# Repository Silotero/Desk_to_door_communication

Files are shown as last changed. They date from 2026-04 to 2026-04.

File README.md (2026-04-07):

# Desk_to_door_communication

This is a 2-part project. Its purpose is to establish basic communication beetween a person that is sitting inside the room at his desk and a visitor standing outside his rooms door. It allows the person in the room to display certain information (such as what he is doing, is he busy, can the person outside easily enter) at a screen outside near the doors, for the visitor. The visitor can also send certain information such as announcing who he is, to the person at the desk. Also displayed at a small screen.
Other functions are a webhosted camera view of the outside of the room, a RFID tag reader that displays certain information on the screen after a readout and also plays a song on the speakers.

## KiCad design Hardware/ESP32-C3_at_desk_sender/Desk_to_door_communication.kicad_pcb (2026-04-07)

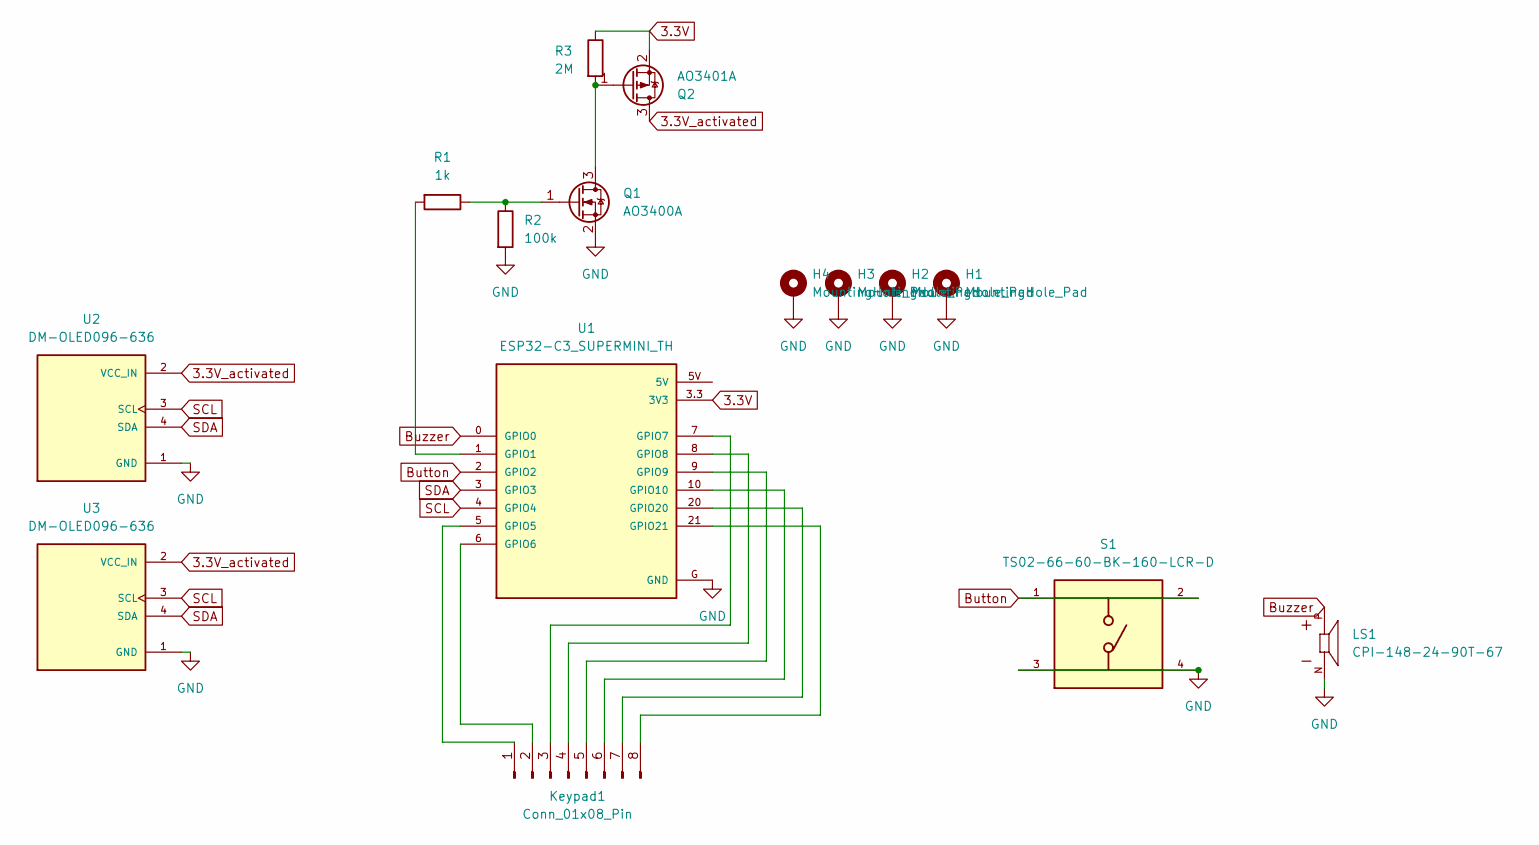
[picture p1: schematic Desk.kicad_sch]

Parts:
H1, H2, H3, H4: MountingHole_Pad; MountingHole_2.2mm_M2_DIN965_Pad_TopBottom
Keypad1: Conn_01x08_Pin; PinHeader_1x08_P2.54mm_Vertical
LS1: CPI-148-24-90T-67; XDCR_CPI-148-24-90T-67; PARTREV 1
Q1: AO3400A; SOT-23
Q2: AO3401A; SOT-23
R1: 1k; R_0805_2012Metric
R2: 100k; R_0805_2012Metric
R3: 2M; R_0805_2012Metric
S1: TS02-66-60-BK-160-LCR-D; SW_TS02-66-60-BK-160-LCR-D; PARTREV 1.0
U1: ESP32-C3_SUPERMINI_TH; MODULE_ESP32-C3_SUPERMINI_TH
U2, U3: DM-OLED096-636; MODULE_DM-OLED096-636; PARTREV 2018-09-10

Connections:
3.3V: Q2.2 (S), R3.1, U1.3.3 (3V3)
3.3V_activated: Q2.3 (D), U2.2 (VCC_IN), U3.2 (VCC_IN)
Button: S1.1, S1.2, U1.2 (GPIO2)
Buzzer: LS1.P, U1.0 (GPIO0)
GND: H1.1, H2.1, H3.1, H4.1, LS1.N, Q1.2 (S), R2.2, S1.3, S1.4, U1.G (GND), U2.1 (GND), U3.1 (GND)
unnamed: Keypad1.1, U1.5 (GPIO5)
unnamed: Keypad1.2, U1.6 (GPIO6)
unnamed: Keypad1.3, U1.7 (GPIO7)
unnamed: Keypad1.4, U1.8 (GPIO8)
unnamed: Keypad1.5, U1.9 (GPIO9)
unnamed: Keypad1.6, U1.10 (GPIO10)
unnamed: Keypad1.7, U1.20 (GPIO20)
unnamed: Keypad1.8, U1.21 (GPIO21)
unnamed: Q1.3 (D), Q2.1 (G), R3.2
unnamed: Q1.1 (G), R1.1, R2.1
unnamed: R1.2, U1.1 (GPIO1)
SCL: U1.4 (GPIO4), U2.3 (SCL), U3.3 (SCL)
SDA: U1.3 (GPIO3), U2.4 (SDA), U3.4 (SDA)

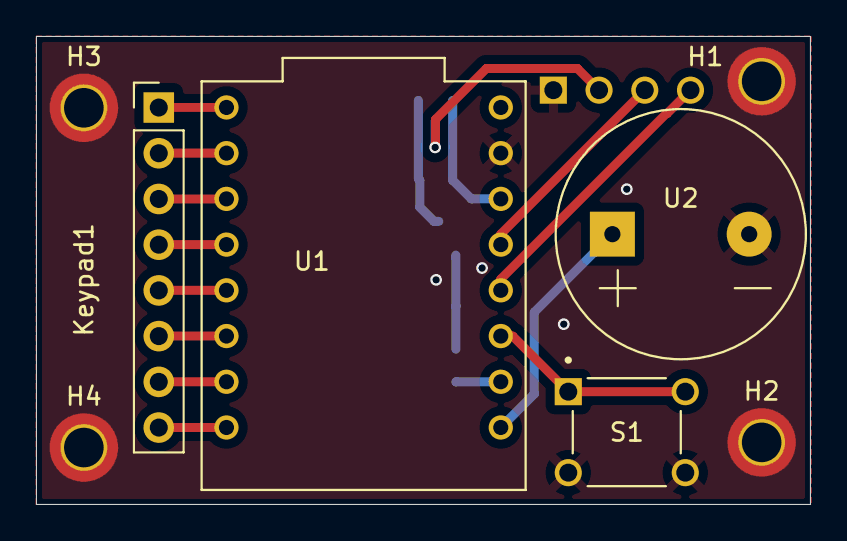
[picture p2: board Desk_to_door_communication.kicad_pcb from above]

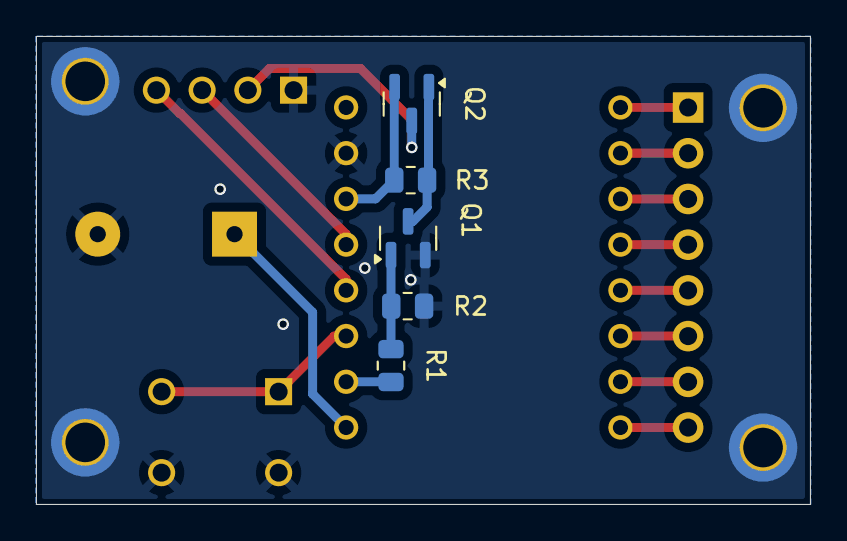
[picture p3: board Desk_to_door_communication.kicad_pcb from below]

Board: 2 copper layers, 43.0 x 26.0 mm, 14 parts (5 on the bottom side), 18 nets.

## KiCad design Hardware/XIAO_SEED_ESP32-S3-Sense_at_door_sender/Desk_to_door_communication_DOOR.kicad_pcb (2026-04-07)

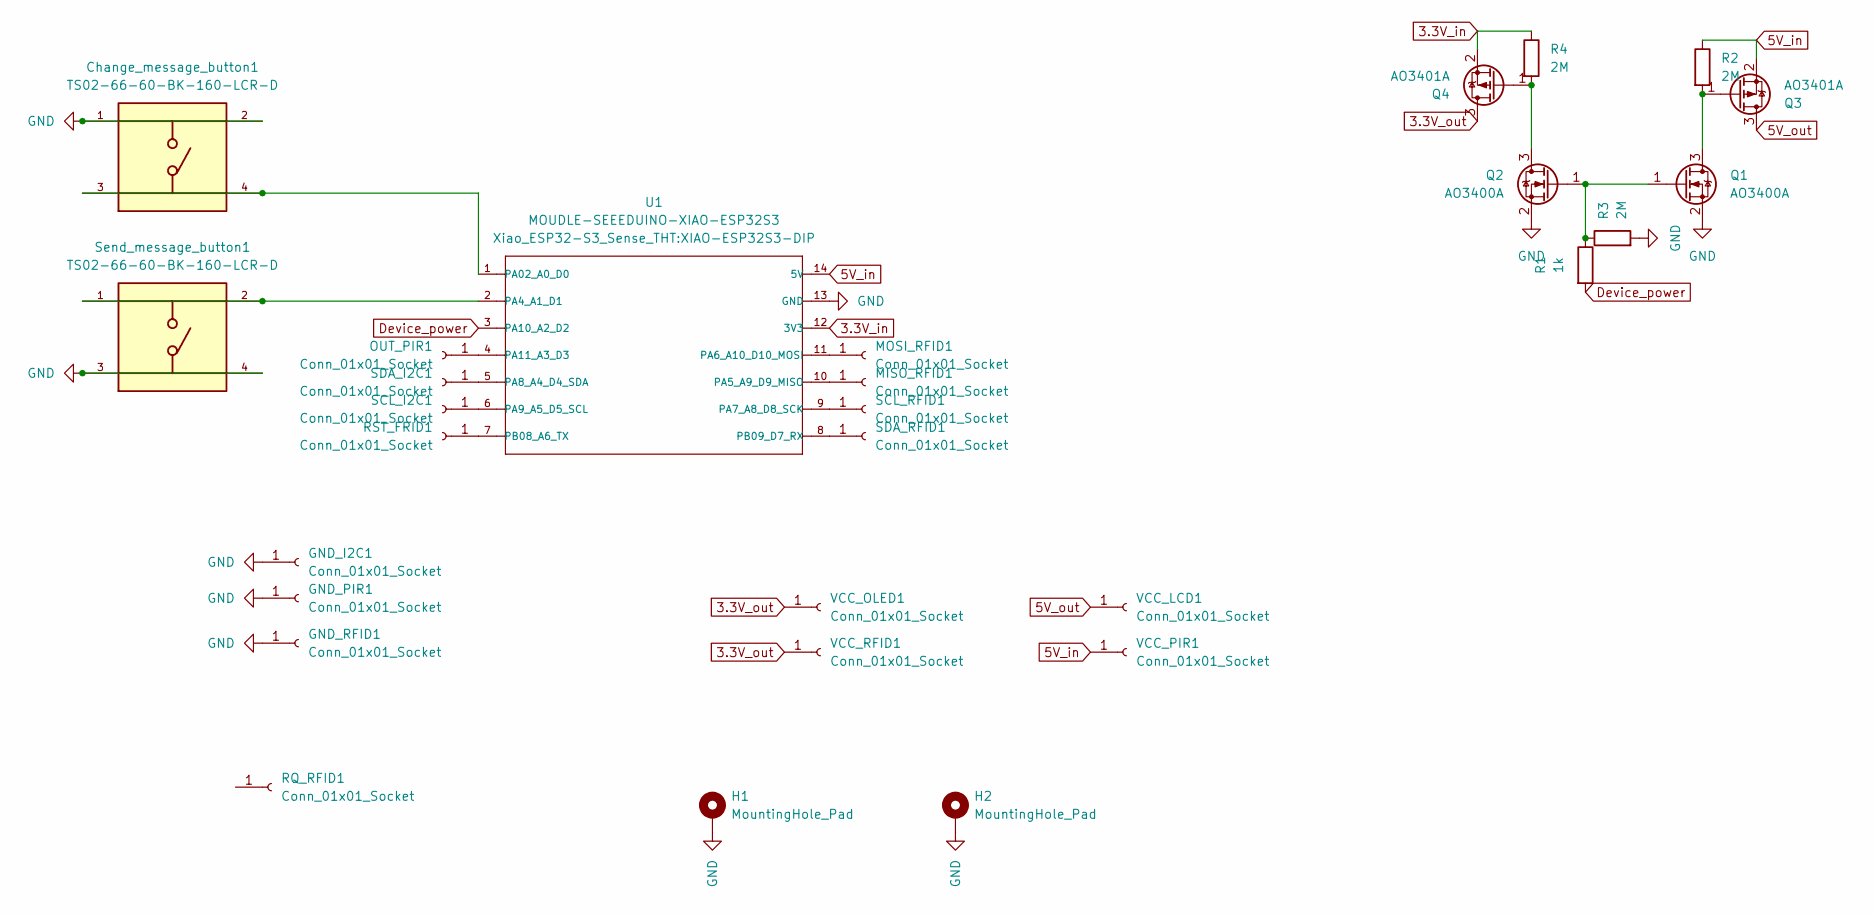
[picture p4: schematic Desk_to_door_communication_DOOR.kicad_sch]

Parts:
Change_message_button1: TS02-66-60-BK-160-LCR-D; SW_TS02-66-60-BK-160-LCR-D; PARTREV 1.0
GND_I2C1: Conn_01x01_Socket; Pin_D1.0mm_L10.0mm
GND_PIR1: Conn_01x01_Socket; Pin_D1.0mm_L10.0mm
GND_RFID1: Conn_01x01_Socket; Pin_D1.0mm_L10.0mm
H1, H2: MountingHole_Pad; MountingHole_2.2mm_M2_DIN965_Pad
MISO_RFID1: Conn_01x01_Socket; Pin_D1.0mm_L10.0mm
MOSI_RFID1: Conn_01x01_Socket; Pin_D1.0mm_L10.0mm
OUT_PIR1: Conn_01x01_Socket; Pin_D1.0mm_L10.0mm
Q1, Q2: AO3400A; SOT-23
Q3, Q4: AO3401A; SOT-23
R1: 1k; R_0805_2012Metric
R2, R3, R4: 2M; R_0805_2012Metric
RQ_RFID1: Conn_01x01_Socket; Pin_D1.0mm_L10.0mm
RST_FRID1: Conn_01x01_Socket; Pin_D1.0mm_L10.0mm
SCL_I2C1: Conn_01x01_Socket; Pin_D1.0mm_L10.0mm
SCL_RFID1: Conn_01x01_Socket; Pin_D1.0mm_L10.0mm
SDA_I2C1: Conn_01x01_Socket; Pin_D1.0mm_L10.0mm
SDA_RFID1: Conn_01x01_Socket; Pin_D1.0mm_L10.0mm
Send_message_button1: TS02-66-60-BK-160-LCR-D; SW_TS02-66-60-BK-160-LCR-D; PARTREV 1.0
U1: MOUDLE-SEEEDUINO-XIAO-ESP32S3; XIAO-ESP32S3-DIP
VCC_LCD1: Conn_01x01_Socket; Pin_D1.0mm_L10.0mm
VCC_OLED1: Conn_01x01_Socket; Pin_D1.0mm_L10.0mm
VCC_PIR1: Conn_01x01_Socket; Pin_D1.0mm_L10.0mm
VCC_RFID1: Conn_01x01_Socket; Pin_D1.0mm_L10.0mm

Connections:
3.3V_in: Q4.2 (S), R4.1, U1.12 (3V3)
3.3V_out: Q4.3 (D), VCC_OLED1.1, VCC_RFID1.1
5V_in: Q3.2 (S), R2.1, U1.14 (5V), VCC_PIR1.1
5V_out: Q3.3 (D), VCC_LCD1.1
Device_power: R1.2, U1.3 (PA10_A2_D2)
GND: Change_message_button1.1, Change_message_button1.2, GND_I2C1.1, GND_PIR1.1, GND_RFID1.1, H1.1, H2.1, Q1.2 (S), Q2.2 (S), R3.2, Send_message_button1.3, Send_message_button1.4, U1.13 (GND)
unnamed: MISO_RFID1.1, U1.10 (PA5_A9_D9_MISO)
unnamed: MOSI_RFID1.1, U1.11 (PA6_A10_D10_MOSI)
unnamed: OUT_PIR1.1, U1.4 (PA11_A3_D3)
unnamed: Q1.3 (D), Q3.1 (G), R2.2
unnamed: Q1.1 (G), Q2.1 (G), R1.1, R3.1
unnamed: Q2.3 (D), Q4.1 (G), R4.2
unnamed: RST_FRID1.1, U1.7 (PB08_A6_TX)
unnamed: SCL_I2C1.1, U1.6 (PA9_A5_D5_SCL)
unnamed: SCL_RFID1.1, U1.9 (PA7_A8_D8_SCK)
unnamed: SDA_I2C1.1, U1.5 (PA8_A4_D4_SDA)
unnamed: SDA_RFID1.1, U1.8 (PB09_D7_RX)
unnamed: Change_message_button1.3, Change_message_button1.4, U1.1 (PA02_A0_D0)
unnamed: Send_message_button1.1, Send_message_button1.2, U1.2 (PA4_A1_D1)

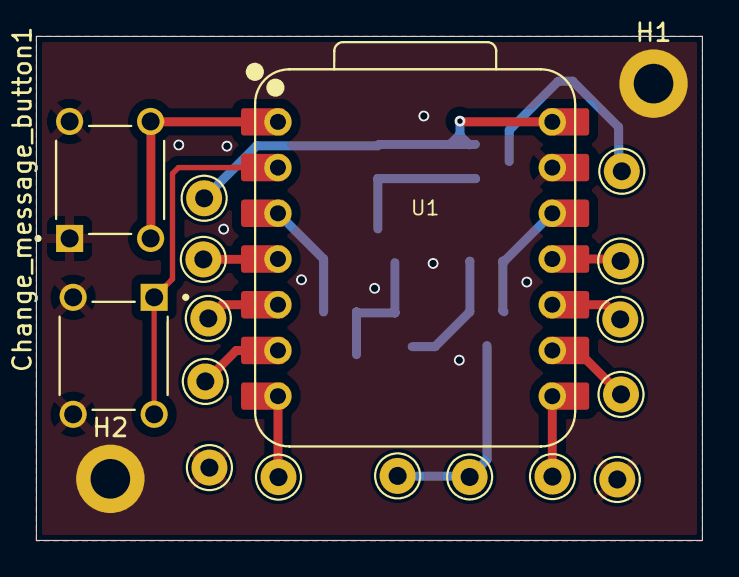
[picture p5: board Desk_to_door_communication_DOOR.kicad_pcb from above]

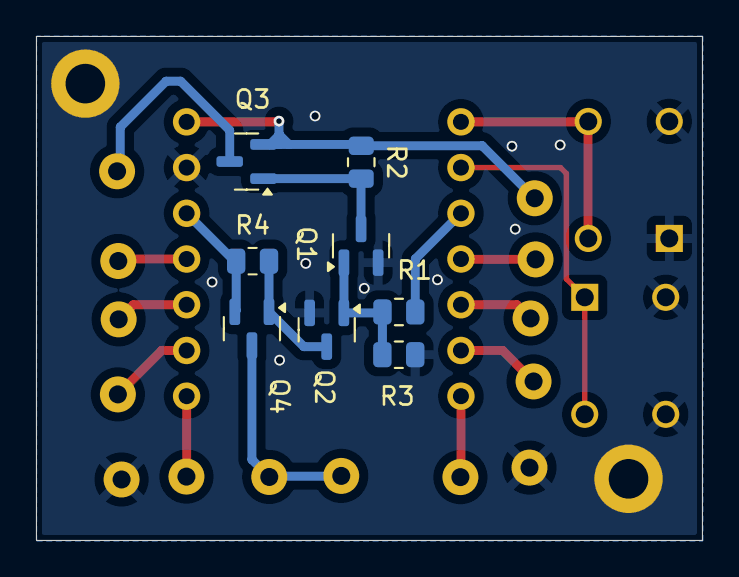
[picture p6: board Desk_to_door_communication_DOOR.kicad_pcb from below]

Board: 2 copper layers, 37.0 x 28.0 mm, 27 parts (8 on the bottom side), 19 nets.

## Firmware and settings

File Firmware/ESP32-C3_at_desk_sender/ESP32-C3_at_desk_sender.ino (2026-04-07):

#include <esp_now.h> // Library for espnow
#include <WiFi.h> //Library for WiFi
#include <Wire.h> //library for I2C
#include <Adafruit_GFX.h>
#include <Adafruit_SSD1306.h> //Libraries for OLED displays
#include "driver/rtc_io.h" //library for rtc gpio functions
#include <time.h> // library for time functions, here used for getting and storing time from the internet
#include "esp_sleep.h"

#define DEBUG 1 //change to 0 to disable debugging, all the debbuging won't be compiled

#if DEBUG
  #define DEBUG_PRINT(x)    Serial.print(x)
  #define DEBUG_PRINTLN(x)  Serial.println(x)
  #define DEBUG_PRINTF(...) Serial.printf(__VA_ARGS__)
#else
  #define DEBUG_PRINT(x)
  #define DEBUG_PRINTLN(x)
  #define DEBUG_PRINTF(...)
#endif

TwoWire I2C_default = TwoWire(0); //create new i2c lines

const uint8_t SMALL_OLED_SCREEN_WIDTH = 128; // OLED display width, in pixels
const uint8_t SMALL_OLED_SCREEN_HEIGHT = 32; // OLED display height, in pixels
// Declaration for SSD1306 display connected using I2C
const int SMALL_OLED_RESET = -1; // Reset pin # (or -1 if sharing Arduino reset pin or not having a reset pin)
const uint8_t SMALL_OLED_SCREEN_ADDRESS = 0x3C; //OLED screen I2C address
//create and object SMALL_OLED
Adafruit_SSD1306 SMALL_OLED(SMALL_OLED_SCREEN_WIDTH, SMALL_OLED_SCREEN_HEIGHT, &I2C_default, SMALL_OLED_RESET);
bool SMALL_display_nodisplay = true; //boolean for checking if new message should be displayed

const uint8_t BIG_OLED_SCREEN_WIDTH = 128; // OLED display width, in pixels
const uint8_t BIG_OLED_SCREEN_HEIGHT = 64; // OLED display height, in pixels
// Declaration for SSD1306 display connected using I2C
const int BIG_OLED_RESET = -1; // Reset pin # (or -1 if sharing Arduino reset pin or not having a reset pin)
const uint8_t BIG_OLED_SCREEN_ADDRESS = 0x3D; //OLED screen I2C address
//create and object BIG_OLED
Adafruit_SSD1306 BIG_OLED(BIG_OLED_SCREEN_WIDTH, BIG_OLED_SCREEN_HEIGHT, &I2C_default, BIG_OLED_RESET);
bool BIG_display_nodisplay = true; //boolean for checking if new message should be displayed
//pins for rows and columns as well as getting the sizes of the arrays

const char* SMALLoledMessages[] = {
  "",                 // 0 - unused
  "",          // 1
  "",// 2
  "WAZNE",            // 3
  "MAMA",             // 4
  "TATA",             // 5
  "DANIELA",          // 6
  "MACIEK",           // 7
};

portMUX_TYPE key_mux = portMUX_INITIALIZER_UNLOCKED; // a mux to block the same variables from being accessed at the same time, used beacuse of RTOS
portMUX_TYPE message_mux = portMUX_INITIALIZER_UNLOCKED;
portMUX_TYPE sleep_mux = portMUX_INITIALIZER_UNLOCKED;
portMUX_TYPE repeat_message_mux = portMUX_INITIALIZER_UNLOCKED;

//task handles for RTOS tasks, needed to check their memory usage
TaskHandle_t buttonWatcherHandle = NULL;
TaskHandle_t SMALLOLEDWatcherHandle = NULL;
TaskHandle_t BIGOLEDWatcherHandle = NULL;
TaskHandle_t KEYPADWatcherHandle = NULL;

SemaphoreHandle_t i2cMutex;

const gpio_num_t ROWS[] = {GPIO_NUM_5,GPIO_NUM_6,GPIO_NUM_7,GPIO_NUM_8};
const gpio_num_t COLS[] = {GPIO_NUM_9,GPIO_NUM_10,GPIO_NUM_20,GPIO_NUM_21};
const uint8_t NUM_ROWS = sizeof(ROWS)/sizeof(gpio_num_t);
const uint8_t NUM_COLS = sizeof(COLS)/sizeof(gpio_num_t);

//create array of the keypad
const char KEYS[NUM_ROWS][NUM_COLS] = {
  {'1', '2', '3', 'A'},
  {'4', '5', '6', 'B'},
  {'7', '8', '9', 'C'},
  {'*', '0', '#', 'D'}
};

// ===========================
// Enter your WiFi credentials
// ===========================
const char* ssid = "Orange_Swiatlowod_7310";
const char* password = "dcCv5oqVPdfbcGQ9U9";

//variables for buttons
gpio_num_t wakeup_sleep_pin = GPIO_NUM_2; //gpio for wakeup;
gpio_num_t buzzer_pin = GPIO_NUM_0;
gpio_num_t Displays_power_pin = GPIO_NUM_1; //pin that powers a mosfet for powering the displays
gpio_num_t SDA_PIN = GPIO_NUM_4; //new i2c sda pin, being the same as the default
gpio_num_t SCL_PIN = GPIO_NUM_3; //new i2c scl pin, being the same as the default
const uint8_t debounce_delay = 130;

bool should_sleep = true;

uint8_t broadcastAddress[] = {0x74,0x4D,0xBD,0x98,0x92,0x18};

const unsigned long uS_TO_S_FACTOR = 1000000;  // conversion factor for seconds to microseconds
unsigned long last_wakeup_time;
const unsigned int keep_awake_for = 10000;

bool message_to_be_sent = false;

String success;

typedef struct struct_message {
  char keypad_char;
} struct_message;
struct_message dataToSend;

typedef struct struct_message2 {
  int message_char;
} struct_message2;
struct_message2 incomingData;

int message_data = 3; //char for receiveing message char

const uint8_t maxRetries = 6; //retries for connecting wifi
int Retries = 0;

RTC_DATA_ATTR char key = '1'; // char for holding a char read from the keypad
char last_key = '1'; // char for holding last key char from the keypad

esp_now_peer_info_t peerInfo;

// Callback when data is sent
void OnDataSent(const wifi_tx_info_t *info, esp_now_send_status_t status) {
  DEBUG_PRINT("\r\nLast Packet Send Status:\t");
  DEBUG_PRINTLN(status == ESP_NOW_SEND_SUCCESS ? "Delivery Success" : "Delivery Fail");
  if (status == 0){
    success = "Delivery Success :)";
    portENTER_CRITICAL(&repeat_message_mux)
    message_to_be_sent = false;
    portEXIT_CRITICAL(&repeat_message_mux)
  }
  else{
    success = "Delivery Fail :(";
    portENTER_CRITICAL(&repeat_message_mux)
    message_to_be_sent = true;
    portEXIT_CRITICAL(&repeat_message_mux)
  }
}

// Callback when data is received
void OnDataRecv(const uint8_t * mac, const uint8_t *incomingBytes, int len) {
  memcpy(&incomingData, incomingBytes, sizeof(incomingData));
  DEBUG_PRINT("Bytes received: ");
  DEBUG_PRINTLN(len);
  DEBUG_PRINT("Value received: ");
  portENTER_CRITICAL(&message_mux);
  message_data = incomingData.message_char;
  DEBUG_PRINTLN(message_data);
  SMALL_display_nodisplay = true;
  last_wakeup_time = millis();
  portEXIT_CRITICAL(&message_mux);
  digitalWrite(buzzer_pin, HIGH);
  delay(100);
  digitalWrite(buzzer_pin, LOW);
}


void synchronizeTime() {
  configTime(0, 0, "pool.ntp.org", "time.nist.gov");
  // Set Poland time zone with DST (daylight saving time, basically the time switch beetween winter and summer) support
  setenv("TZ", "CET-1CEST,M3.5.0/2,M10.5.0/3", 1);
  tzset();
  struct tm timeinfo; // special struct from time.h library, represents broken-down time — meaning it stores the components of a calendar time (like year, month, day, hour, minute, second) in a human-readable form.
  while (!getLocalTime(&timeinfo)) {
    delay(1000);
    DEBUG_PRINTLN("Waiting for NTP time sync...");
  }
}

void prep_for_deep_sleep () {
  struct tm timeheld;
  getLocalTime(&timeheld);
  int hour = timeheld.tm_hour;
  int min = timeheld.tm_min;
  int sec = timeheld.tm_sec;
  DEBUG_PRINT("Godzina ");
  DEBUG_PRINTLN(hour);
  DEBUG_PRINT("Minuta ");
  DEBUG_PRINTLN(min);
  DEBUG_PRINT("Ile będzie spać ");
  DEBUG_PRINTLN(14 - min%15);
  if (hour >= 7 && hour <= 23 ) esp_sleep_enable_timer_wakeup(((14 - min%15) * 60 + (60 - sec))* uS_TO_S_FACTOR); // enable timer based wakeup if inside hours, wakeup at 15 parts of an hour
    esp_deep_sleep_enable_gpio_wakeup(1ULL << wakeup_sleep_pin, ESP_GPIO_WAKEUP_GPIO_LOW);
    delay(100);
    esp_deep_sleep_start();// deep sleep start, no code after it will be performed if triggered
}

//Debounce function for buttons
bool debounce(int button_index) {
  static unsigned long last_debounce_time[2] = {0,0};
  unsigned long now = millis();
  if(now - last_debounce_time[button_index] >= debounce_delay) {
    last_debounce_time[button_index] = now;
    return true;
  }
  return false;
}

void printKeypadLayout() {
  for(int x = 0; x < NUM_ROWS; x++) {
    for(int y = 0; y < NUM_COLS; y++) {
      DEBUG_PRINT(KEYS[x][y]);
      DEBUG_PRINT("\t");
    }
    DEBUG_PRINT("\n");
  }
  DEBUG_PRINT("\n");
}

void showOLEDMessage(uint8_t index) {
  if (xSemaphoreTake(i2cMutex, portMAX_DELAY) == pdTRUE) {
    SMALL_OLED.clearDisplay();
    SMALL_OLED.setTextColor(WHITE);
    SMALL_OLED.setCursor(0,0);
    if (index != 6) {
      SMALL_OLED.setTextSize(3);  // Default large text
      SMALL_OLED.print(SMALLoledMessages[index]);
    }
    else {
      SMALL_OLED.setTextSize(2);
      SMALL_OLED.print(SMALLoledMessages[index]);
    }
    SMALL_OLED.display();
    xSemaphoreGive(i2cMutex);
  }
}

//functions for FreeRTOS - functions that run in parrallel, basically run in the background without interrupting and waiting for each other

void TaskButtonWatcher(void *pvParameters) {
  for(;;) {
    if (digitalRead(wakeup_sleep_pin) == LOW && debounce(1)) {
      prep_for_deep_sleep();
    }
    vTaskDelay(40 / portTICK_PERIOD_MS);  // Poll every 40 ms
  }
}
//checking if the small oled display should be updated
void TaskSmallOledUpdater(void *pvParameters) {
  for (;;) {
    bool should_update = false;
    int msg_val;
    uint16_t delay_k = 400;
    portENTER_CRITICAL(&message_mux);
    should_update = SMALL_display_nodisplay;
    SMALL_display_nodisplay = false;
    msg_val = message_data;
    message_data = 0;
    portEXIT_CRITICAL(&message_mux);
    
    if (should_update) {
      showOLEDMessage(msg_val);
    }
  }
}
//checking if the bid display should be updated
void TaskBIGOledUpdater(void *pvParameters) {
  for (;;) {
    bool should_update2 = false;
    char key_value;
    uint16_t delay_k = 400;
    portENTER_CRITICAL(&key_mux);
    key_value = key;
    should_update2 = BIG_display_nodisplay;
    BIG_display_nodisplay = false;
    DEBUG_PRINTLN(key_value);
    if (key != 'H' && key != '#') {
      last_key = key;
      dataToSend.keypad_char = key;
    }
    if (key == '#') {
      key = 'H';
      BIG_display_nodisplay = true;
    }
    else if (key == 'H' || key =='C') {
      key = last_key;
      BIG_display_nodisplay = true;;
    }
    portEXIT_CRITICAL(&key_mux);
    if (should_update2) {

      if (xSemaphoreTake(i2cMutex, portMAX_DELAY) == pdTRUE) {
        switch (key_value) {
          case '0':
            break;
          case 'H':
            BIG_OLED.clearDisplay();
            BIG_OLED.setTextSize(2);
            BIG_OLED.setTextColor(WHITE);
            BIG_OLED.setCursor(22,22);
            BIG_OLED.print("WYSLANO");
            BIG_OLED.display();
            delay_k = 1000;
            break;
          case '1':
            BIG_OLED.clearDisplay();
            BIG_OLED.setTextSize(3);
            BIG_OLED.setTextColor(WHITE);
            BIG_OLED.setCursor(12,0);
            BIG_OLED.print("MOZNA");
            BIG_OLED.setCursor(12,31);
            BIG_OLED.print("WEJSC");
            break;
          case '2':
            BIG_OLED.clearDisplay();
            BIG_OLED.setTextSize(2);
            BIG_OLED.setTextColor(WHITE);
            BIG_OLED.setCursor(43,10);
            BIG_OLED.print("MAM");
            BIG_OLED.setCursor(15,40);
            BIG_OLED.print("EGZAMIN");
            break;
          case '3':
            BIG_OLED.clearDisplay();
            BIG_OLED.setTextSize(2);
            BIG_OLED.setTextColor(WHITE);
            BIG_OLED.setCursor(36,10);
            BIG_OLED.print("UCZE");
            BIG_OLED.setCursor(43,40);
            BIG_OLED.print("SIE");
            break;
          case '4':
            BIG_OLED.clearDisplay();
            BIG_OLED.setTextSize(2);
            BIG_OLED.setTextColor(WHITE);
            BIG_OLED.setCursor(43,10);
            BIG_OLED.print("NIE");
            BIG_OLED.setCursor(8,40);
            BIG_OLED.print("WCHODZIC");
            break;
          case '5':
            BIG_OLED.clearDisplay();
            BIG_OLED.setTextSize(2);
            BIG_OLED.setTextColor(WHITE);
            BIG_OLED.setCursor(22,10);
            BIG_OLED.print("GRAM Z");
            BIG_OLED.setCursor(36,40);
            BIG_OLED.print("KIMS");
            break;
          case '6':
            BIG_OLED.clearDisplay();
            BIG_OLED.setTextSize(2);
            BIG_OLED.setTextColor(WHITE);
            BIG_OLED.setCursor(1,10);
            BIG_OLED.print("ROZMAWIAM");
            BIG_OLED.setCursor(22,40);
            BIG_OLED.print("Z KIMS");
            break;
          case '7':
            BIG_OLED.clearDisplay();
            BIG_OLED.setTextSize(2);
            BIG_OLED.setTextColor(WHITE);
            BIG_OLED.setCursor(8,10);
            BIG_OLED.print("NAJPIERW");
            BIG_OLED.setCursor(15,40);
            BIG_OLED.print("ZAPUKAJ");
            break;
          case '8':
            BIG_OLED.clearDisplay();
            BIG_OLED.setTextSize(2);
            BIG_OLED.setTextColor(WHITE);
            BIG_OLED.setCursor(15,10);
            BIG_OLED.print("CZY COS");
            BIG_OLED.setCursor(15,40);
            BIG_OLED.print("WAZNEGO?");
            break;
          case '9':
            BIG_OLED.clearDisplay();
            BIG_OLED.setTextSize(2);
            BIG_OLED.setTextColor(WHITE);
            BIG_OLED.setCursor(1,22);
            BIG_OLED.print("ZAMKNIETE");
            break;
          case '#': {
            esp_err_t result = esp_now_send(broadcastAddress, (uint8_t *) &dataToSend , sizeof(dataToSend));
            break;
          }
        }
        BIG_OLED.display();
      }
    }
    xSemaphoreGive(i2cMutex);
    vTaskDelay(delay_k / portTICK_PERIOD_MS);
  }
}

void TaskreadKey(void *pvParameters) {
  for(;;) {
    for(int x = 0; x < NUM_ROWS; x++) {
      for(int row = 0; row < NUM_ROWS; row++) digitalWrite(ROWS[row], x != row);
      for(int y = 0; y < NUM_COLS; y++) {
        if(!digitalRead(COLS[y])){
          while(!digitalRead(COLS[y])){}
          vTaskDelay(150 / portTICK_PERIOD_MS);
          portENTER_CRITICAL(&key_mux);
          key = KEYS[x][y];
          BIG_display_nodisplay = true;
          portEXIT_CRITICAL(&key_mux);
        }
      }
    }
    vTaskDelay(70 / portTICK_PERIOD_MS);
  }
}

void setup() {
  // put your setup code here, to run once:
  //Initialize serial communication
  #if DEBUG
    Serial.begin(9600);   // Start the Serial Monitor
    delay(100);             // Give it time to connect (especially for USB serial)
    DEBUG_PRINTLN("Debugging started...");
  #endif
  pinMode(buzzer_pin, OUTPUT);

  // Set device as a Wi-Fi Station
  WiFi.mode(WIFI_AP_STA);
  WiFi.begin(ssid, password);
  WiFi.setSleep(false);

  while (WiFi.status() != WL_CONNECTED) {
    delay(400);
    Retries += 1;
    DEBUG_PRINT(".");
    if (Retries == maxRetries)
    {
      WiFi.disconnect(true);
      delay(700); 
      WiFi.begin(ssid, password);
      DEBUG_PRINTLN("Retrying");
      Retries = 0;
    }
  }
  DEBUG_PRINTLN("WiFi connected");
  DEBUG_PRINT(WiFi.localIP());
  DEBUG_PRINTLN("' to connect");

  // Init ESP-NOW
  if (esp_now_init() != ESP_OK) {
    DEBUG_PRINTLN("Error initializing ESP-NOW");
    return;
  }

  // Once ESPNow is successfully Init, we will register for Send CB to
  
  // Register peer
  memcpy(peerInfo.peer_addr, broadcastAddress, 6);
  peerInfo.channel = 0;  
  peerInfo.encrypt = false;
  
  // Add peer        
  if (esp_now_add_peer(&peerInfo) != ESP_OK){
    DEBUG_PRINTLN("Failed to add peer");
    return;
  }

  // Register for a callback function that will be called when data is received
  esp_now_register_recv_cb(esp_now_recv_cb_t(OnDataRecv));

    // get the status of Trasnmitted packet
  esp_now_register_send_cb(OnDataSent);

  pinMode(wakeup_sleep_pin, INPUT_PULLUP);
  synchronizeTime();
  esp_sleep_wakeup_cause_t wakeup_reason = esp_sleep_get_wakeup_cause();//checking what caused the wake up and taking appropriate actions after finding out
  if (wakeup_reason == ESP_SLEEP_WAKEUP_TIMER) {
    DEBUG_PRINTLN("Woke up from timer");
    delay(20000);
    portENTER_CRITICAL(&message_mux);
    last_wakeup_time = millis();
    portEXIT_CRITICAL(&message_mux);
    prep_for_deep_sleep();
  } 
  else if (wakeup_reason ==  ESP_SLEEP_WAKEUP_GPIO) {
    DEBUG_PRINTLN("Woke up from external GPIO");
    portENTER_CRITICAL(&message_mux);
    last_wakeup_time = millis();
    portEXIT_CRITICAL(&message_mux);
    portENTER_CRITICAL(&sleep_mux);
    should_sleep = false;
    portEXIT_CRITICAL(&sleep_mux);
  } 
  else {
    DEBUG_PRINTLN("Fresh boot or other wake-up reason");
  }
  //set button pins modes
  pinMode(Displays_power_pin, OUTPUT);
  digitalWrite(Displays_power_pin, HIGH);
  delay(40);

  I2C_default.begin(SDA_PIN,SCL_PIN, 100000);
  delay(10);

  i2cMutex = xSemaphoreCreateMutex();

  if (i2cMutex == NULL) {
    DEBUG_PRINTLN("Failed to create I2C mutex!");
  }
  delay(10);

  //setup keypad buttons modes
  for(int x = 0; x < NUM_ROWS; x++) {
    pinMode(ROWS[x], OUTPUT);
    digitalWrite(ROWS[x], LOW);
  }

  for(int x = 0; x < NUM_COLS; x++) {
    pinMode(COLS[x], INPUT_PULLUP);
  }
  
  DEBUG_PRINTLN("Keypad initialized");
  printKeypadLayout();

  if (xSemaphoreTake(i2cMutex, portMAX_DELAY) == pdTRUE) {
    //initial setup for SMALL_OLED
    if(!SMALL_OLED.begin(SSD1306_SWITCHCAPVCC, SMALL_OLED_SCREEN_ADDRESS)) {
    Serial.println(F("SSD1306 allocation failed"));
    for(;;); // Don't proceed, loop forever
    }
    xSemaphoreGive(i2cMutex);
  }
  if (xSemaphoreTake(i2cMutex, portMAX_DELAY) == pdTRUE) {
    //initial setup for BIG_OLED
    if(!BIG_OLED.begin(SSD1306_SWITCHCAPVCC, BIG_OLED_SCREEN_ADDRESS)) {
    Serial.println(F("SSD1306 allocation failed"));
    for(;;); // Don't proceed, loop forever
    }
    xSemaphoreGive(i2cMutex);
  }

// initialize the tasks that use FreeRTOS
  xTaskCreatePinnedToCore(
  TaskreadKey,     // Task function
  "KEYPAD Watcher",      // Name of task
  1024,                // Stack size in words (2048 = 8 KB)
  NULL,                // Task input parameter
  1,                   // Priority (1 is default)
  &KEYPADWatcherHandle,                // Task handle (not needed here)
  0                    // Core to run on (0 or 1)
);

  xTaskCreatePinnedToCore(
  TaskButtonWatcher,     // Task function
  "Button Watcher",      // Name of task
  768,                // Stack size in words (2048 = 8 KB)
  NULL,                // Task input parameter
  1,                   // Priority (1 is default)
  &buttonWatcherHandle,                // Task handle (not needed here)
  0                    // Core to run on (0 or 1)
);

xTaskCreatePinnedToCore(
  TaskBIGOledUpdater,
  "BIG OLED Updater",
  2048,
  NULL,
  1,
  &BIGOLEDWatcherHandle,
  0
);

xTaskCreatePinnedToCore(
  TaskSmallOledUpdater,
  "SMALL OLED Updater",
  2048,
  NULL,
  1,
  &SMALLOLEDWatcherHandle,
  0
);
}

void loop() {
  // put your main code here, to run repeatedly:
  unsigned long now = millis();
  unsigned long last_wakeup_time_copy;
  portENTER_CRITICAL(&message_mux);
  last_wakeup_time_copy = last_wakeup_time;
  portEXIT_CRITICAL(&message_mux);
  if (now - last_wakeup_time_copy > keep_awake_for && should_sleep) {
    DEBUG_PRINTLN("Idzie spac bo dlugo nic");
    prep_for_deep_sleep();
  }
  portENTER_CRITICAL(&repeat_message_mux)
  bool message_send = message_to_be_sent;
  portEXIT_CRITICAL(&repeat_message_mux)
  if (message_send) {
    struct tm timeheld;
    getLocalTime(&timeheld);
    int hour = timeheld.tm_hour;
    int min = timeheld.tm_min;
    int sec = timeheld.tm_sec;
    if (hour >= 7 && hour <= 23 && min%15 == 0 && sec >= 10 ) {
      esp_err_t result = esp_now_send(broadcastAddress, (uint8_t *) &dataToSend , sizeof(dataToSend));
    }
  }
  #if DEBUG
    static unsigned long last_debug = 0;
    if (now - last_debug > 1000) {
      DEBUG_PRINT("ButtonWatcher stack: ");
      DEBUG_PRINTLN(uxTaskGetStackHighWaterMark(buttonWatcherHandle));

      DEBUG_PRINT("KEYPADWatcher stack: ");
      DEBUG_PRINTLN(uxTaskGetStackHighWaterMark(KEYPADWatcherHandle));

      DEBUG_PRINT("BIGOLEDWatcher stack: ");
      DEBUG_PRINTLN(uxTaskGetStackHighWaterMark(BIGOLEDWatcherHandle));

      DEBUG_PRINT("SMALLOLEDWatcher stack: ");
      DEBUG_PRINTLN(uxTaskGetStackHighWaterMark(SMALLOLEDWatcherHandle));

      last_debug = now;
    }
  #endif
  delay(500);
}

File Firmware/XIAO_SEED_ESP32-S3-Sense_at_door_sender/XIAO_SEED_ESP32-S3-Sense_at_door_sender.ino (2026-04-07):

#include <esp_now.h> // Library for espnow
#include "esp_camera.h"
#include <WiFi.h> //Library for WiFi
#include <LCD_I2C.h>//library for lcd that works with custom i2c pins
#include <Wire.h> //library for I2C
#include <SPI.h> // Library for SPI
#include <MFRC522.h> //rfid reader library
#include <Adafruit_GFX.h>
#include <Adafruit_SSD1306.h> //Libraries for OLED displays
#include "driver/rtc_io.h" //library for rtc gpio functions
#include <time.h> // library for time functions, here used for getting and storing time from the internet
#include "freertos/FreeRTOS.h"
#include "freertos/semphr.h"

#define CAMERA_MODEL_XIAO_ESP32S3 // Has PSRAM

#include "camera_pins.h"

#define PCF_ADDRESS 0x26 // I2C address of the PCF expander

//debbugging area
#define DEBUG 1 //change to 0 to disable debugging, all the debbuging won't be compiled

#if DEBUG
  #define DEBUG_PRINT(x)    Serial.print(x)
  #define DEBUG_PRINTLN(x)  Serial.println(x)
  #define DEBUG_PRINTF(...) Serial.printf(__VA_ARGS__)
#else
  #define DEBUG_PRINT(x)
  #define DEBUG_PRINTLN(x)
  #define DEBUG_PRINTF(...)
#endif

const uint8_t OLED_SCREEN_WIDTH = 128; // OLED display width, in pixels
const uint8_t OLED_SCREEN_HEIGHT = 32; // OLED display height, in pixels
// Declaration for SSD1306 display connected using I2C
const int OLED_RESET = -1; // Reset pin # (or -1 if sharing Arduino reset pin or not having a reset pin)
const uint8_t OLED_SCREEN_ADDRESS = 0x3C; //OLED screen I2C address

gpio_num_t button_choice_pin = GPIO_NUM_1; //button for chosing a message to be sent
gpio_num_t button_send_pin = GPIO_NUM_2; //button for sending the chosen message
gpio_num_t motion_wakeup_pin = GPIO_NUM_4; //gpio for motion sensor wakeup;
gpio_num_t Displays_power_pin = GPIO_NUM_3; //pin that powers a mosfet for powering the displays
gpio_num_t SDA_PIN = GPIO_NUM_5; //new i2c sda pin, being the same as the default
gpio_num_t SCL_PIN = GPIO_NUM_6; //new i2c scl pin, being the same as the default
gpio_num_t SS_PIN = GPIO_NUM_44;
gpio_num_t RST_PIN = GPIO_NUM_43;
gpio_num_t SCK_PIN = GPIO_NUM_7;
gpio_num_t MOSI_PIN = GPIO_NUM_9;
gpio_num_t MISO_PIN = GPIO_NUM_8; //ALL 4 SPI pins  and a reset pin for the rfid reader

MFRC522 mfrc522(SS_PIN, RST_PIN);  // Create MFRC522 instance
String Card = "4369BC1C";
String Brelok = "C3B8DF0D";
String tagID = "";

TwoWire I2C_default = TwoWire(0);
//create and object OLED
Adafruit_SSD1306 OLED(OLED_SCREEN_WIDTH, OLED_SCREEN_HEIGHT, &I2C_default, OLED_RESET);

const uint8_t LCD_SCREEN_WIDTH = 16; // LCD display width, in pixels
const uint8_t LCD_SCREEN_HEIGHT = 2; // LCD display height, in pixels
const uint8_t LCD_SCREEN_ADDRESS = 0x27; // LCD screen I2C address
//create an object lcd
LCD_I2C lcd(I2C_default, LCD_SCREEN_ADDRESS, LCD_SCREEN_WIDTH, LCD_SCREEN_HEIGHT); // I2C address 0x27, 16 column and 2 rows

//CUSTOM CHARS FOR LCD
byte Lock[8] = {
0b01110,
0b10001,
0b10001,
0b11111,
0b11011,
0b11011,
0b11111,
0b00000
};

byte Skull[8] = {
0b00000,
0b01110,
0b10101,
0b11011,
0b01110,
0b01110,
0b00000,
0b00000
};

byte Bell[8] = {
0b00100,
0b01110,
0b01110,
0b01110,
0b11111,
0b00000,
0b00100,
0b00000
};

byte Check[8] = {
0b00000,
0b00001,
0b00011,
0b10110,
0b11100,
0b01000,
0b00000,
0b00000
};

byte Speaker[8] = {
0b00001,
0b00011,
0b01111,
0b01111,
0b01111,
0b00011,
0b00001,
0b00000
};

const char* oledMessages[] = {
  "",                 // 0 - unused
  "WYSLANO",          // 1
  "WYBIERZ WIADOMOSC",// 2
  "WAZNE",            // 3
  "MAMA",             // 4
  "TATA",             // 5
  "DANIELA",          // 6
  "MACIEK",           // 7
  "",                 // 8 - unused
  "MASTER",           // 9
  "DAMIAN"            // 10
};

String success;
int message_value = 2; //value for keeping which message is to be displayed or sent
bool display_nodisplay = true; //boolean for checking if new message should be displayed

//Structs for sending and receiveing data, likely to change
typedef struct struct_message {
  char keypad_char;
} struct_message;
struct_message incomingData;

typedef struct struct_message2 {
  int message_char;
} struct_message2;
struct_message2 dataToSend;

char keypad_data = '0';//char for receiveing keypad chars
RTC_DATA_ATTR char last_keypad_data = '0';

const uint8_t debounce_delay = 130; //debounce delay time

//mac address of the arduino_nano_esp32-s3
uint8_t broadcastAddress[] = {0x50,0x78,0x7D,0x41,0x56,0x48}; //this is for arduino nano esp32 mac address, the one on the left is one of the c3 super mini {0x34,0x85,0x18,0x7B,0xD8,0x78};
esp_now_peer_info_t peerInfo;
//sleep variables
const unsigned long uS_TO_S_FACTOR = 1000000;  // conversion factor for seconds to microseconds
unsigned long last_wakeup_time;
unsigned long long keep_awake_for = 10000;

const uint8_t maxRetries = 6; //retries for connecting wifi
int Retries = 0;

portMUX_TYPE mux = portMUX_INITIALIZER_UNLOCKED; // a mux to block the same variables from being accessed at the same time, used beacuse of RTOS

//task handles for RTOS tasks, needed to check their memory usage
TaskHandle_t buttonWatcherHandle = NULL;
TaskHandle_t RFIDWatcherHandle = NULL;
TaskHandle_t OLEDWatcherHandle = NULL;
TaskHandle_t LCDWatcherHandle = NULL;

SemaphoreHandle_t i2cMutex;

// Callback when data is sent through espnow
void OnDataSent(const wifi_tx_info_t *info, esp_now_send_status_t status) {
  DEBUG_PRINT("\r\nLast Packet Send Status:\t");
  DEBUG_PRINTLN(status == ESP_NOW_SEND_SUCCESS ? "Delivery Success" : "Delivery Fail");
  if (status == 0){
    success = "Delivery Success :)";
  }
  else{
    success = "Delivery Fail :(";
  }
}

// Callback when data is received through espnow
void OnDataRecv(const uint8_t * mac, const uint8_t *incomingBytes, int len) {
  memcpy(&incomingData, incomingBytes, sizeof(incomingData));
  // DEBUG_PRINT("Bytes received: ");
  // DEBUG_PRINTLN(len);
  // DEBUG_PRINT("Value received: ");
  portENTER_CRITICAL(&mux);
  keypad_data = incomingData.keypad_char;
  //DEBUG_PRINTLN(keypad_data);
  last_keypad_data = keypad_data;
  last_wakeup_time = millis();
  if (keypad_data == 'C')  {
    keep_awake_for = 60000 * 10;
  }
  else keep_awake_for = 10000;
  portEXIT_CRITICAL(&mux);
}

//Debounce function for buttons
bool debounce(int button_index) {
  static unsigned long last_debounce_time[2] = {0,0};
  unsigned long now = millis();
  if(now - last_debounce_time[button_index] >= debounce_delay) {
    last_debounce_time[button_index] = now;
    return true;
  }
  return false;
}

// Sets all the bits to 1 of the PCF expander
void resetPlayer() {
  if (xSemaphoreTake(i2cMutex, portMAX_DELAY) == pdTRUE) {
    I2C_default.beginTransmission(PCF_ADDRESS);
    I2C_default.write(0xFF); // 1111 1111 (All High)
    I2C_default.endTransmission();
    xSemaphoreGive(i2cMutex);
  }
}
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

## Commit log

2026-04-07 Added finished firmware
    [partitions.csv]
2026-04-07 Added finished hardware kicad files
    [Desk.kicad_sch, Desk_to_door_communication.kicad_pcb, Desk_to_door_communication.kicad_sch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]
